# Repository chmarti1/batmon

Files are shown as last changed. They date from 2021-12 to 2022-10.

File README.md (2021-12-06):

#BatMon

A battery monitor system using the LabJack U3 DAQ
---
## In this README
- About
- License
- Warnings

## About
This repository includes files for a PC board design, Bill-of-Materials (BOM), and code for monitoring a battery from a Linux computer.  These materials are intended for information and inspiration; they do not constitute a complete instruction set.

The designed system uses a U3 DAQ to perform analog measurements and a temperature -measurement.  A shunt resistor provides small (+/-0.1V) signal indicating current to and from the battery, and direct connection to the battery terminals provides a measurement of the battery voltage.

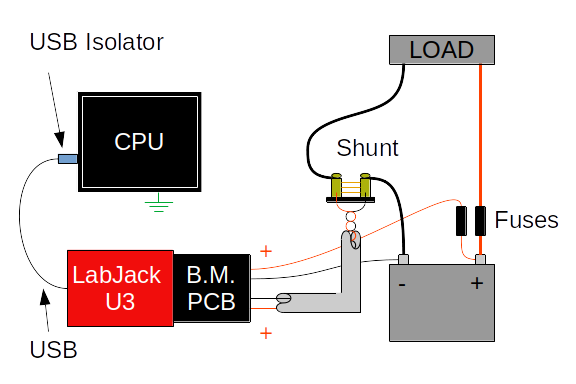
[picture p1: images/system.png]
System Diagram

**Figure 1** A system overview

I designed this system on a 12V AGM SLA battery, but it can be applied on battery arrays of other chemistries as well.

## License
BatMon: A battery monitoring system using the LabJack U3.  
Copyright (c) 2021 Christopher R. Martin PhD

These materials are released under the [GNU GPLv3](https://www.gnu.org/licenses/gpl-3.0.en.html).  This program is free software: you can redistribute it and/or modify it under the terms of the GNU General Public License as published by the Free Software Foundation, either version 3 of the License, or (at your option) any later version.

This program is distributed in the hope that it will be useful, but WITHOUT ANY WARRANTY; without even the implied warranty of MERCHANTABILITY or FITNESS FOR A PARTICULAR PURPOSE.  See the GNU General Public License for more details.

You should have received a copy of the GNU General Public License along with this program.  If not, see https://www.gnu.org/licenses/gpl-3.0.en.html .

## Warnings
- Working with power electronics can be dangerous and should only be done by qualified individuals.
- Special care should be taken to avoid accidental short-circuits
- This work is shared without warranty or suitability for a specific purpose.  
- This work should not be used in systems where failure may cause injury, loss of life, or damage to property.
- The performance of the designs shared here depend on workmanship and the sufficient care taken during calibration and installation.
- For safety, all connections to the positive terminal of the battery should be fused to limit the flow of current.

## Circuit

The circuit design is shown in [circuit.pdf](./images/circuit.pdf), and the PC board layout is shown below.  The DB-15 connector on the right-hand side connects to the LabJack U3 DB-15 connection.  There are four screw terminals on the left-hand side that permit the shunt and terminal measurements.  All inputs are reverse polarity and over-voltage tolerant up to 50V.

There are five low-current indicator LEDs (two red and three green).  The first red LED is tied to a special ALARM circuit, which also fires a buzzer.  The buzzer can be switched off manually by a toggle switch mounted at SW1 (every buzzer needs an off switch).

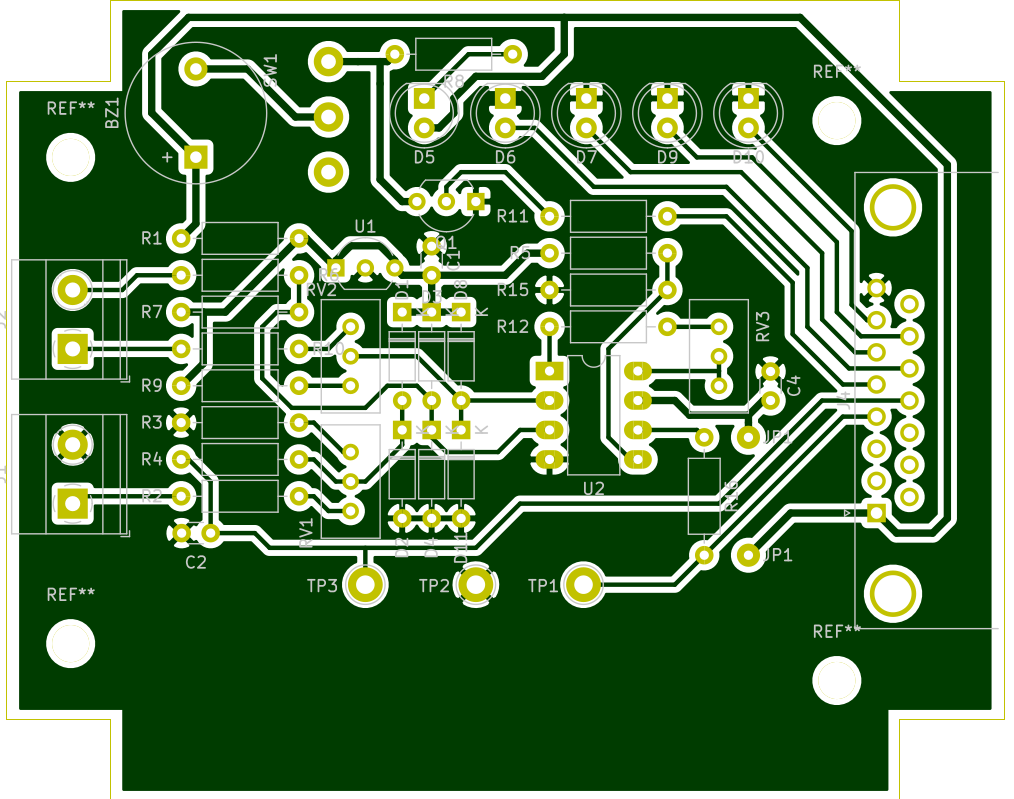
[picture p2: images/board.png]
Board Design


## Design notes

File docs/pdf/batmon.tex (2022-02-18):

\documentclass{article}

\title{The BATMON dynamic battery model}
\author{Christopher R. Martin}
\date{\today}

\begin{document}

\maketitle

\section{Electrical Model}

\end{document}

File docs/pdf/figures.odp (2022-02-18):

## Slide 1

+ Voltage Loss (VL) -

R1

R2

+

Open-Circuit Voltage

(VOC)

+

+

Terminal Voltage

(VT)

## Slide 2

CURRENT

LOAD

Initial internal resistance

tC

Final internal resistance

TIME

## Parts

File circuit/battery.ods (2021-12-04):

Reference | Quantity | Order | Value | Digikey PN (primary) | Digikey PN (secondary) | Footprint
BZ1 | 1 | 1 | CMI-1295IC-0585T | 2223-CMI-1295IC-0585T-ND |  | Buzzer_Beeper:Buzzer_12x9.5RM7.6 | EVERY device with a buzzer should have an ALARM OFF switch.
C4 C1 C2 | 3 |  | 1u | BC1168TR-ND |  | Capacitor_THT:C_Disc_D3.0mm_W1.6mm_P2.50mm
D1 D2 D3 D4 D11 D8 | 6 | 10 | 1N3595 | 1N3595-ND |  | Diode_THT:D_DO-35_SOD27_P7.62mm_Horizontal
D5 D6 | 2 | 1 | RED,10mA | 516-1328-ND |  | LED_THT:LED_D5.0mm
D7 D9 D10 | 3 | 1 | GREEN,10mA | 516-1333-ND |  | LED_THT:LED_D5.0mm
J1 J2 | 2 | 2 | Conn_01x02 | 277-1247-ND |  | TerminalBlock_Phoenix:TerminalBlock_Phoenix_MKDS-1,5-2-5.08_1x02_P5.08mm_Horizontal
J4 | 1 | 1 | DB15_Male | 609-1492-ND |  | Connector_Dsub:DSUB-15_Male_Horizontal_P2.77x2.84mm_EdgePinOffset7.70mm_Housed_MountingHolesOffset9.12mm
Q1 | 1 | 1 | PN2222 | PN2222AFS-ND |  | Package_TO_SOT_THT:TO-92_Inline_Wide
R1 | 1 |  | 470 |  |  | Resistor_THT:R_Axial_DIN0207_L6.3mm_D2.5mm_P10.16mm_Horizontal
R12 | 1 |  | 4K7 |  |  | Resistor_THT:R_Axial_DIN0207_L6.3mm_D2.5mm_P10.16mm_Horizontal
R16 R4 | 2 |  | 100 |  |  | Resistor_THT:R_Axial_DIN0207_L6.3mm_D2.5mm_P10.16mm_Horizontal
R3 | 1 | 2 | 1K2_1% | S1.2KCATR-ND |  | Resistor_THT:R_Axial_DIN0207_L6.3mm_D2.5mm_P10.16mm_Horizontal
R5 R2 R15 R7 R6 R9 R10 | 7 | 10 | 10K_1% | RNF14FTD10K0TR-ND |  | Resistor_THT:R_Axial_DIN0207_L6.3mm_D2.5mm_P10.16mm_Horizontal
R8 R11 | 2 | 2 | 270 |  |  | Resistor_THT:R_Axial_DIN0207_L6.3mm_D2.5mm_P10.16mm_Horizontal
RV1 RV2 RV3 | 3 | 3 | 1K, 3362P | 490-2874-ND |  | Potentiometer_THT:Potentiometer_Bourns_3296W_Vertical
SW1 | 1 | 1 | ANT11SF1CQE | 2449-ANT11SF1CQE-ND |  | _batmon:SW_CIT_ANT_SPDT
TP1 TP2 TP3 | 3 | 3 | TestPoint | 36-5280-ND | 36-5281-ND | TestPoint:TestPoint_Loop_D2.60mm_Drill1.6mm_Beaded
U1 | 1 | 1 | TL431LP | 497-15786-1-ND |  | Package_TO_SOT_THT:TO-92_Inline_Wide
U2 | 1 | 1 | AD623AN | 505-AD623BNZ-ND | A120347-ND | Package_DIP:DIP-8_W7.62mm_LongPads
BOX | 1 | 1 | Hammond 1593BBBK | HM1375-ND
SHUNT | 1 | 1 | 1mOhm, .25% | 811-1094-ND
RING TERMINAL, SM | 2 | 25 | #8, 14-16AWG
RING TERMINAL, LG | 6 | 10 | 3/8 4AWG

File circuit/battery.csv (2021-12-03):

Reference | Quantity | Value | Footprint | Datasheet
BZ1 | 1 | CMI-1295IC-0585T | Buzzer_Beeper:Buzzer_12x9.5RM7.6 | ~
C4 C1 C2 | 3 | 1u | Capacitor_THT:C_Disc_D3.0mm_W1.6mm_P2.50mm | ~
D1 D2 D3 D4 D11 D8 | 6 | 1N3595 | Diode_THT:D_DO-35_SOD27_P7.62mm_Horizontal | ~
D5 D6 | 2 | RED,10mA | LED_THT:LED_D5.0mm | ~
D7 D9 D10 | 3 | GREEN,10mA | LED_THT:LED_D5.0mm | ~
J1 J2 | 2 | Conn_01x02 | TerminalBlock_Phoenix:TerminalBlock_Phoenix_MKDS-1,5-2-5.08_1x02_P5.08mm_Horizontal | ~
J4 | 1 | DB15_Male | Connector_Dsub:DSUB-15_Male_Horizontal_P2.77x2.84mm_EdgePinOffset7.70mm_Housed_MountingHolesOffset9.12mm | ~
Q1 | 1 | BS107 | Package_TO_SOT_THT:TO-92_Inline_Wide | http://www.onsemi.com/pub_link/Collateral/BS107-D.PDF
R1 | 1 | 500 | Resistor_THT:R_Axial_DIN0207_L6.3mm_D2.5mm_P10.16mm_Horizontal | ~
R12 | 1 | 4K7 | Resistor_THT:R_Axial_DIN0207_L6.3mm_D2.5mm_P10.16mm_Horizontal | ~
R16 R4 | 2 | 100 | Resistor_THT:R_Axial_DIN0207_L6.3mm_D2.5mm_P10.16mm_Horizontal | ~
R3 | 1 | 1K2_1% | Resistor_THT:R_Axial_DIN0207_L6.3mm_D2.5mm_P10.16mm_Horizontal | ~
R5 R2 R15 R7 R6 R9 R10 | 7 | 10K_1% | Resistor_THT:R_Axial_DIN0207_L6.3mm_D2.5mm_P10.16mm_Horizontal | ~
R8 | 1 | 300 | Resistor_THT:R_Axial_DIN0207_L6.3mm_D2.5mm_P10.16mm_Horizontal | ~
RV1 RV2 RV3 | 3 | 1K, 3362P | Potentiometer_THT:Potentiometer_Bourns_3296W_Vertical | ~
SW1 | 1 | ANT11SF1CQE | _batmon:SW_CIT_ANT_SPDT | ~
TP1 TP2 TP3 | 3 | TestPoint | TestPoint:TestPoint_Loop_D2.60mm_Drill1.6mm_Beaded | ~
U1 | 1 | TL431LP | Package_TO_SOT_THT:TO-92_Inline_Wide | http://www.ti.com/lit/ds/symlink/tl431.pdf
U2 | 1 | AD623AN | Package_DIP:DIP-8_W7.62mm_LongPads | https://www.analog.com/media/en/technical-documentation/data-sheets/AD623.pdf

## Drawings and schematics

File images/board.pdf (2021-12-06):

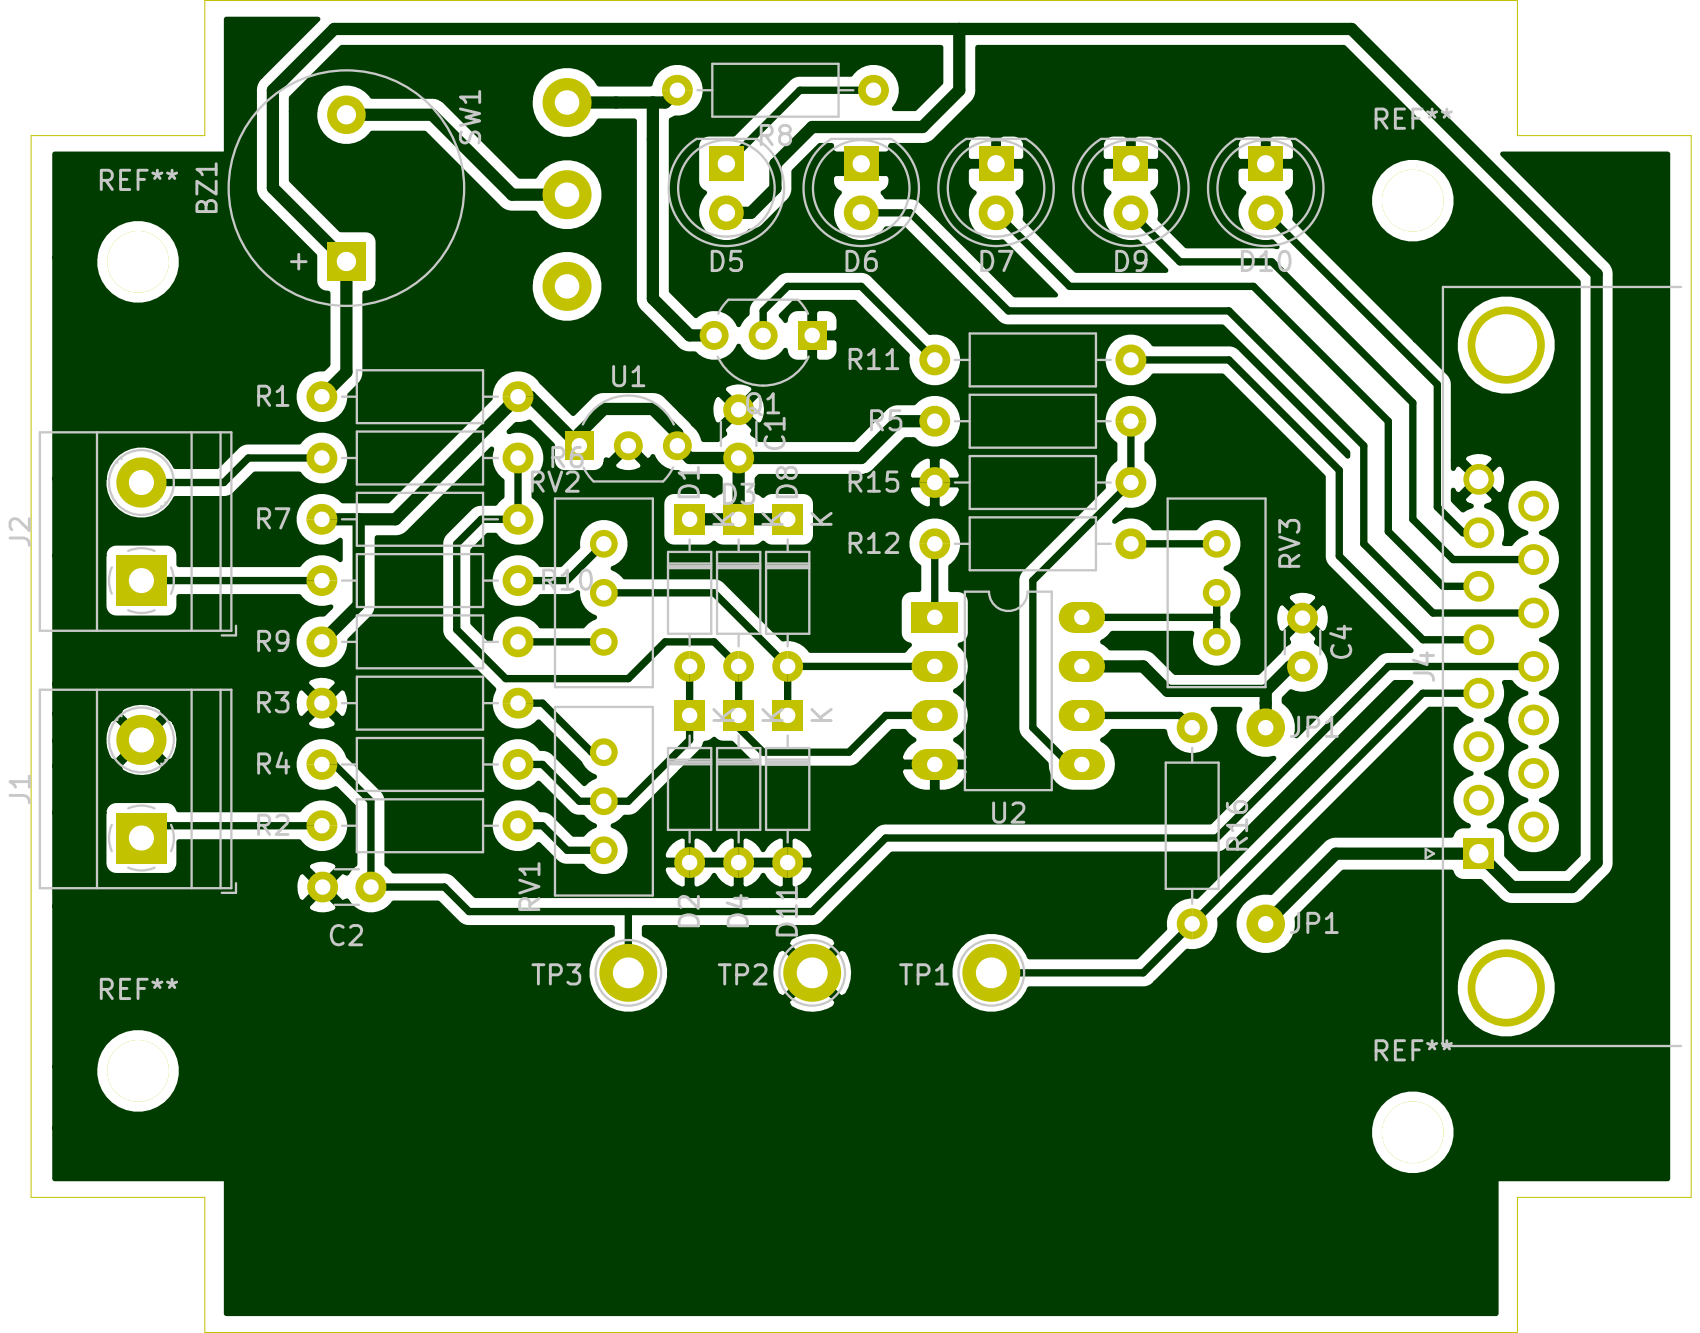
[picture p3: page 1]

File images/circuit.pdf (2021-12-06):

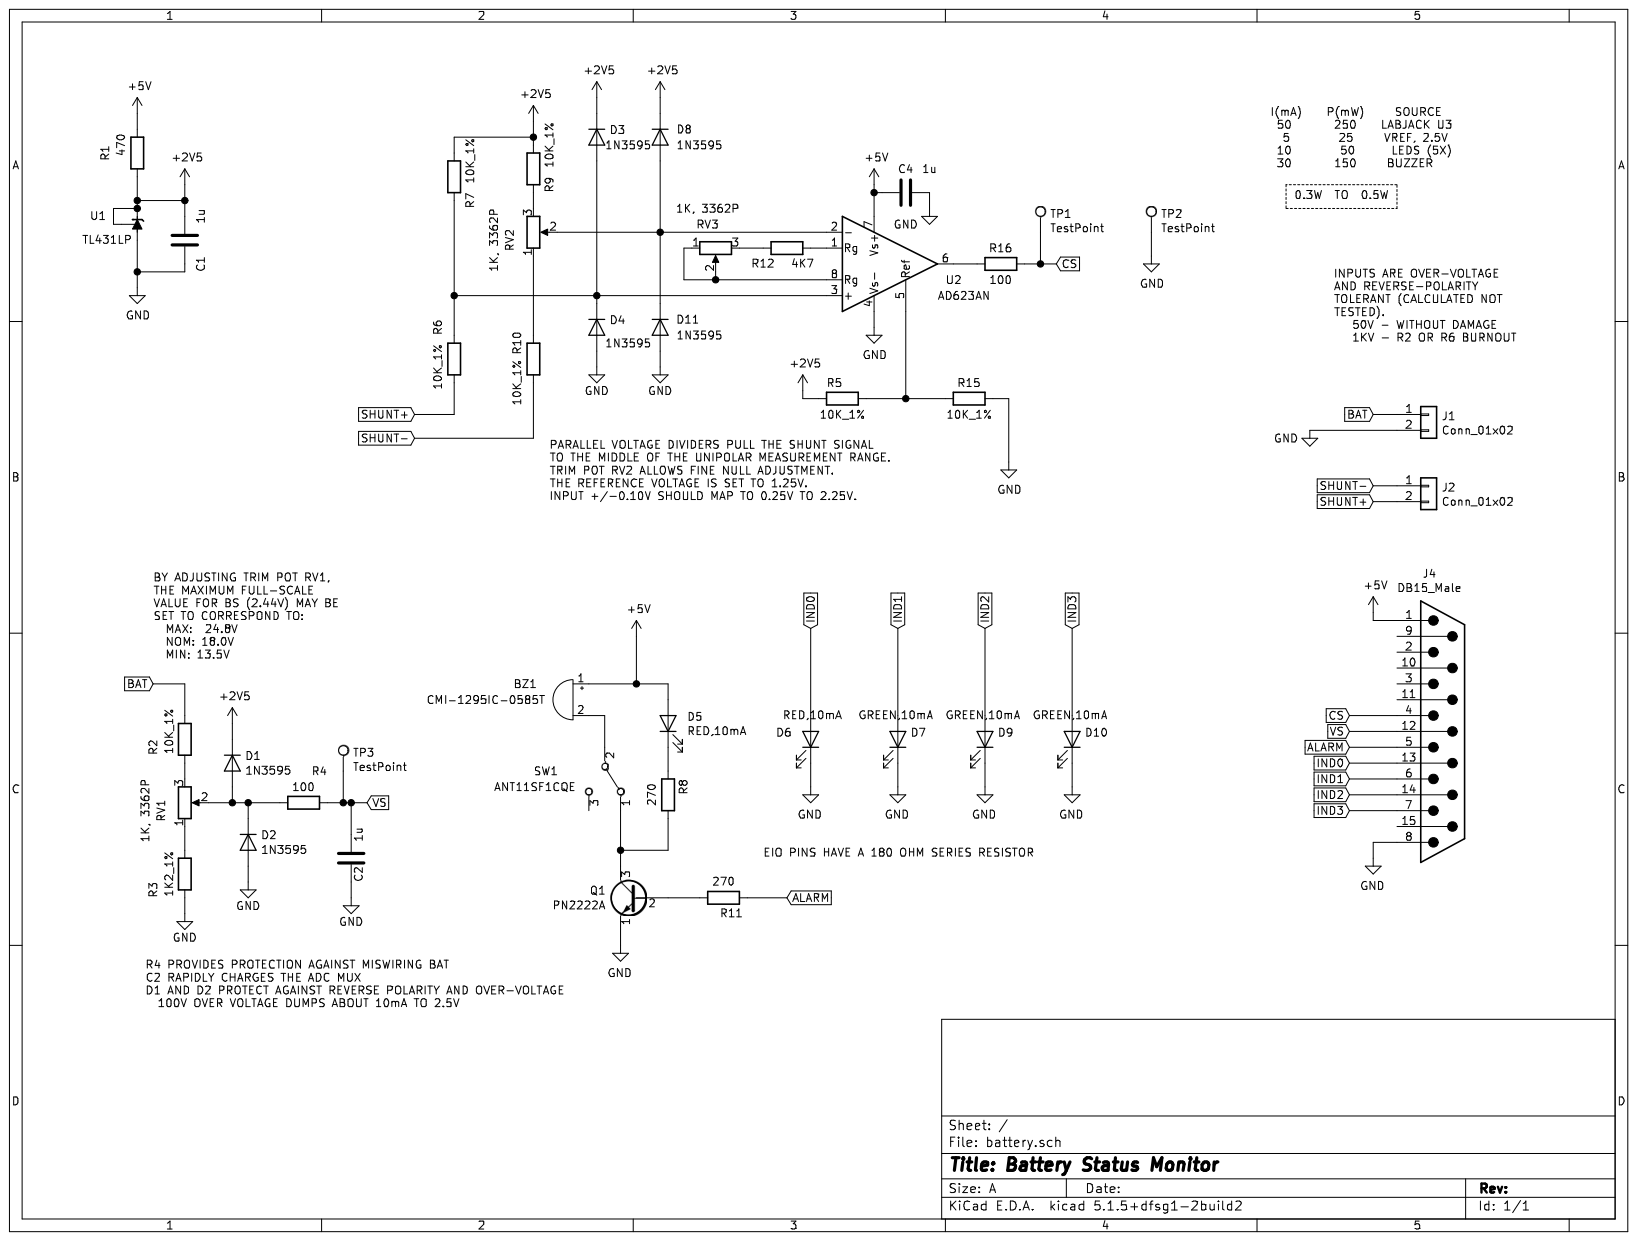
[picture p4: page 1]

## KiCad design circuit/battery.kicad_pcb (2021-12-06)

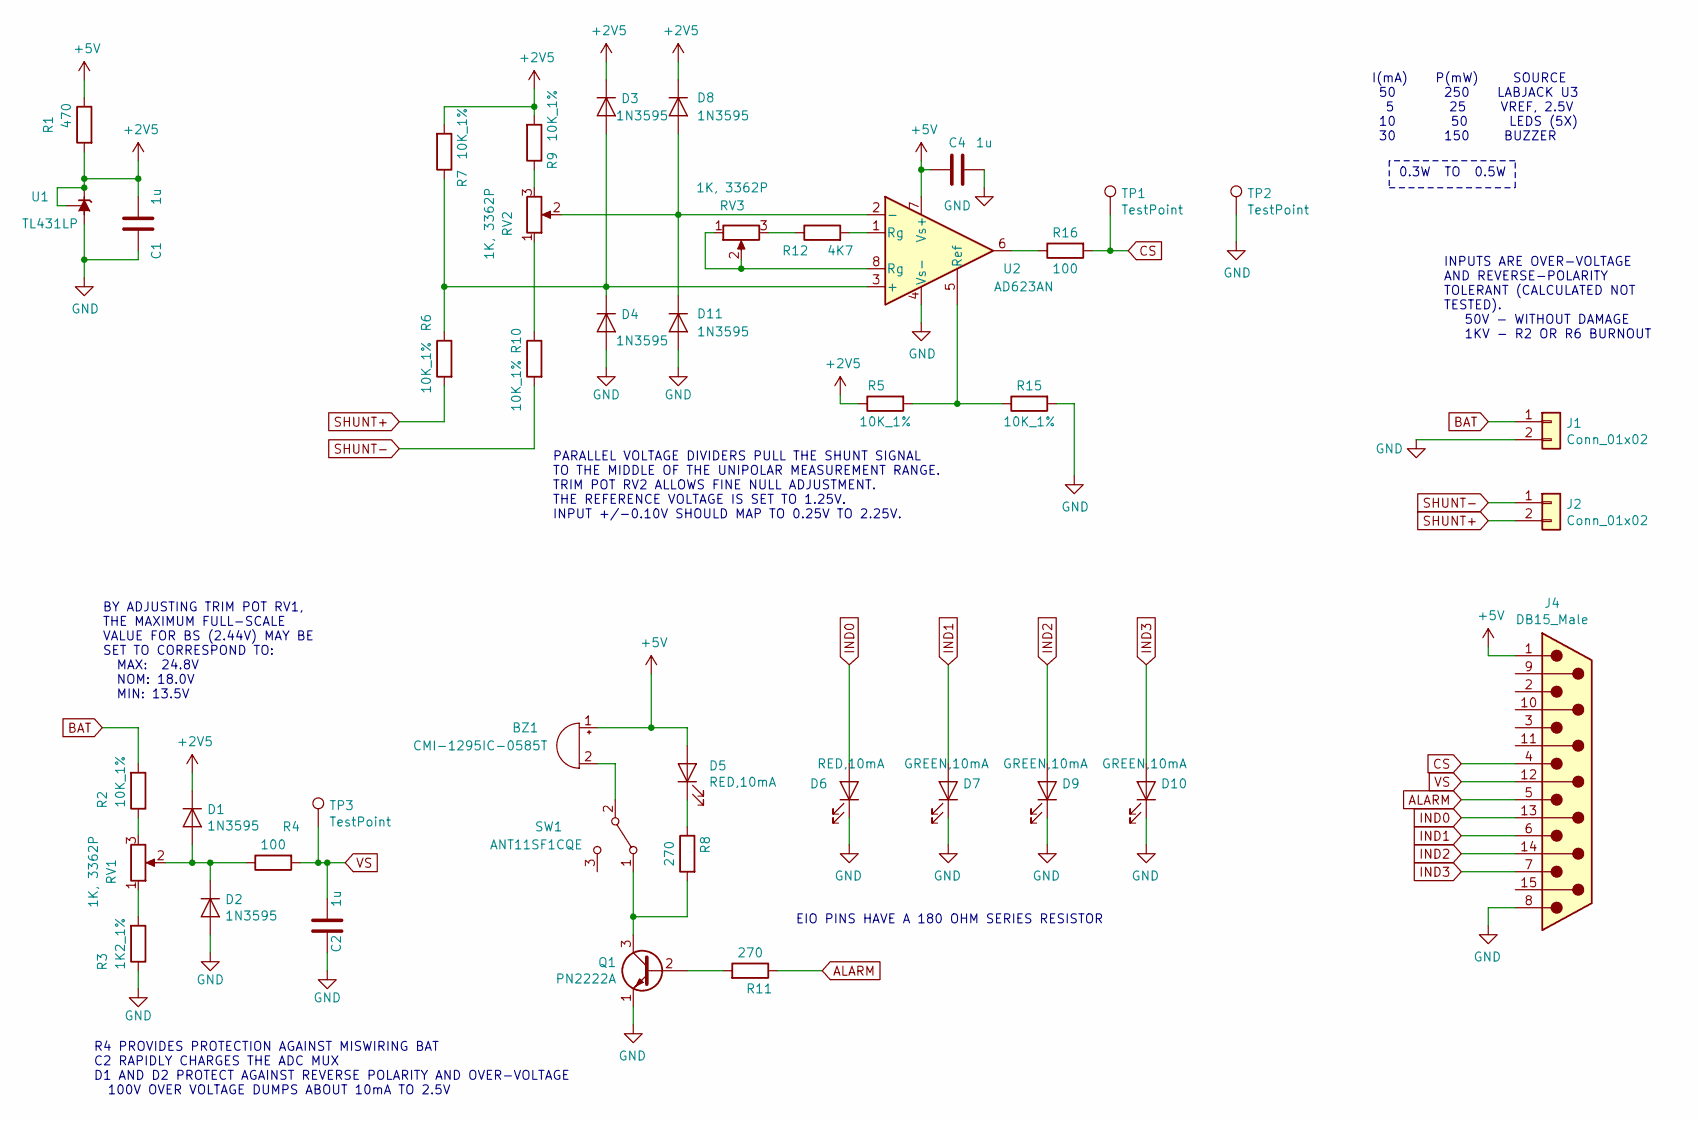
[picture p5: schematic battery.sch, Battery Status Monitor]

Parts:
BZ1: CMI-1295IC-0585T; Buzzer_12x9.5RM7.6
C1, C2, C4: 1u; C_Disc_D3.0mm_W1.6mm_P2.50mm
D1, D2, D3, D4, D8, D11: 1N3595; D_DO-35_SOD27_P7.62mm_Horizontal
D5, D6: RED,10mA; LED_D5.0mm
D7, D9, D10: GREEN,10mA; LED_D5.0mm
J1, J2: Conn_01x02; TerminalBlock_Phoenix_MKDS-1,5-2-5.08_1x02_P5.08mm_Horizont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
J4: DB15_Male; DSUB-15_Male_Horizontal_P2.77x2.84mm_EdgePinOffset7.70mm_Ho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
Q1: PN2222A; TO-92_Inline_Wide
R1: 470; R_Axial_DIN0207_L6.3mm_D2.5mm_P10.16mm_Horizontal
R2, R5, R6, R7, R9, R10, R15: 10K_1%; R_Axial_DIN0207_L6.3mm_D2.5mm_P10.16mm_Horizontal
R3: 1K2_1%; R_Axial_DIN0207_L6.3mm_D2.5mm_P10.16mm_Horizontal
R4, R16: 100; R_Axial_DIN0207_L6.3mm_D2.5mm_P10.16mm_Horizontal
R8, R11: 270; R_Axial_DIN0207_L6.3mm_D2.5mm_P10.16mm_Horizontal
R12: 4K7; R_Axial_DIN0207_L6.3mm_D2.5mm_P10.16mm_Horizontal
RV1, RV2, RV3: 1K, 3362P; Potentiometer_Bourns_3296W_Vertical
SW1: ANT11SF1CQE; SW_CIT_ANT_SPDT
TP1, TP2, TP3: TestPoint; TestPoint_Loop_D2.60mm_Drill1.6mm_Beaded
U1: TL431LP; TO-92_Inline_Wide
U2: AD623AN; DIP-8_W7.62mm_LongPads

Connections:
+2V5: C1.1, D1.1 (K), D3.1 (K), D8.1 (K), R1.2, R5.1, R7.2, R9.2, U1.1 (REF), U1.3 (K)
+5V: BZ1.1 (-), C4.2, D5.2 (A), J4.1, R1.1, U2.7 (Vs+); also elsewhere on the board
ALARM: J4.5, R11.1
BAT: J1.1, R2.2
CS: J4.4, R16.2, TP1.1
GND: C1.2, C2.1, C4.1, D2.2 (A), D4.2 (A), D6.1 (K), D7.1 (K), D9.1 (K), D10.1 (K), D11.2 (A), J1.2, J4.8, Q1.1 (E), R3.1, R15.2, TP2.1, U1.2 (A), U2.4 (Vs-)
IND0: D6.2 (A), J4.13
IND1: D7.2 (A), J4.6
IND2: D9.2 (A), J4.14
IND3: D10.2 (A), J4.7
unnamed: BZ1.2 (+), SW1.2 (B)
unnamed: D1.2 (A), D2.1 (K), R4.1, RV1.2
unnamed: D3.2 (A), D4.1 (K), R6.1, R7.1, U2.3 (+)
unnamed: D5.1 (K), R8.1
unnamed: D8.2 (A), D11.1 (K), RV2.2, U2.2 (-)
unnamed: Q1.2 (B), R11.2
unnamed: Q1.3 (C), R8.2, SW1.1 (A)
unnamed: R2.1, RV1.3
unnamed: R3.2, RV1.1
unnamed: R9.1, RV2.3
unnamed: R10.1, RV2.1
unnamed: R12.1, RV3.3
unnamed: R12.2, U2.1 (Rg)
unnamed: R5.2, R15.1, U2.5 (Ref)
unnamed: R16.1, U2.6
unnamed: RV3.1, RV3.2, U2.8 (Rg)
SHUNT+: J2.2, R6.2
SHUNT-: J2.1, R10.2
VS: C2.2, J4.12, R4.2, TP3.1

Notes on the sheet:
BY ADJUSTING TRIM POT RV1, THE MAXIMUM FULL-SCALE VALUE FOR BS (2.44V) MAY BE SET TO CORRESPOND TO: MAX: 24.8V NOM: 18.0V MIN: 13.5V
R4 PROVIDES PROTECTION AGAINST MISWIRING BAT C2 RAPIDLY CHARGES THE ADC MUX D1 AND D2 PROTECT AGAINST REVERSE POLARITY AND OVER-VOLTAGE 100V OVER VOLTAGE DUMPS ABOUT 10mA TO 2.5V
PARALLEL VOLTAGE DIVIDERS PULL THE SHUNT SIGNAL TO THE MIDDLE OF THE UNIPOLAR MEASUREMENT RANGE. TRIM POT RV2 ALLOWS FINE NULL ADJUSTMENT. THE REFERENCE VOLTAGE IS SET TO 1.25V. INPUT +/-0.10V SHOULD MAP TO 0.25V TO 2.25V.
EIO PINS HAVE A 180 OHM SERIES RESISTOR
I(mA) P(mW) SOURCE 50 250 LABJACK U3 5 25 VREF, 2.5V 10 50 LEDS (5X) 30 150 BUZZER
0.3W TO 0.5W
INPUTS ARE OVER-VOLTAGE AND REVERSE-POLARITY TOLERANT (CALCULATED NOT TESTED). 50V - WITHOUT DAMAGE 1KV - R2 OR R6 BURNOUT

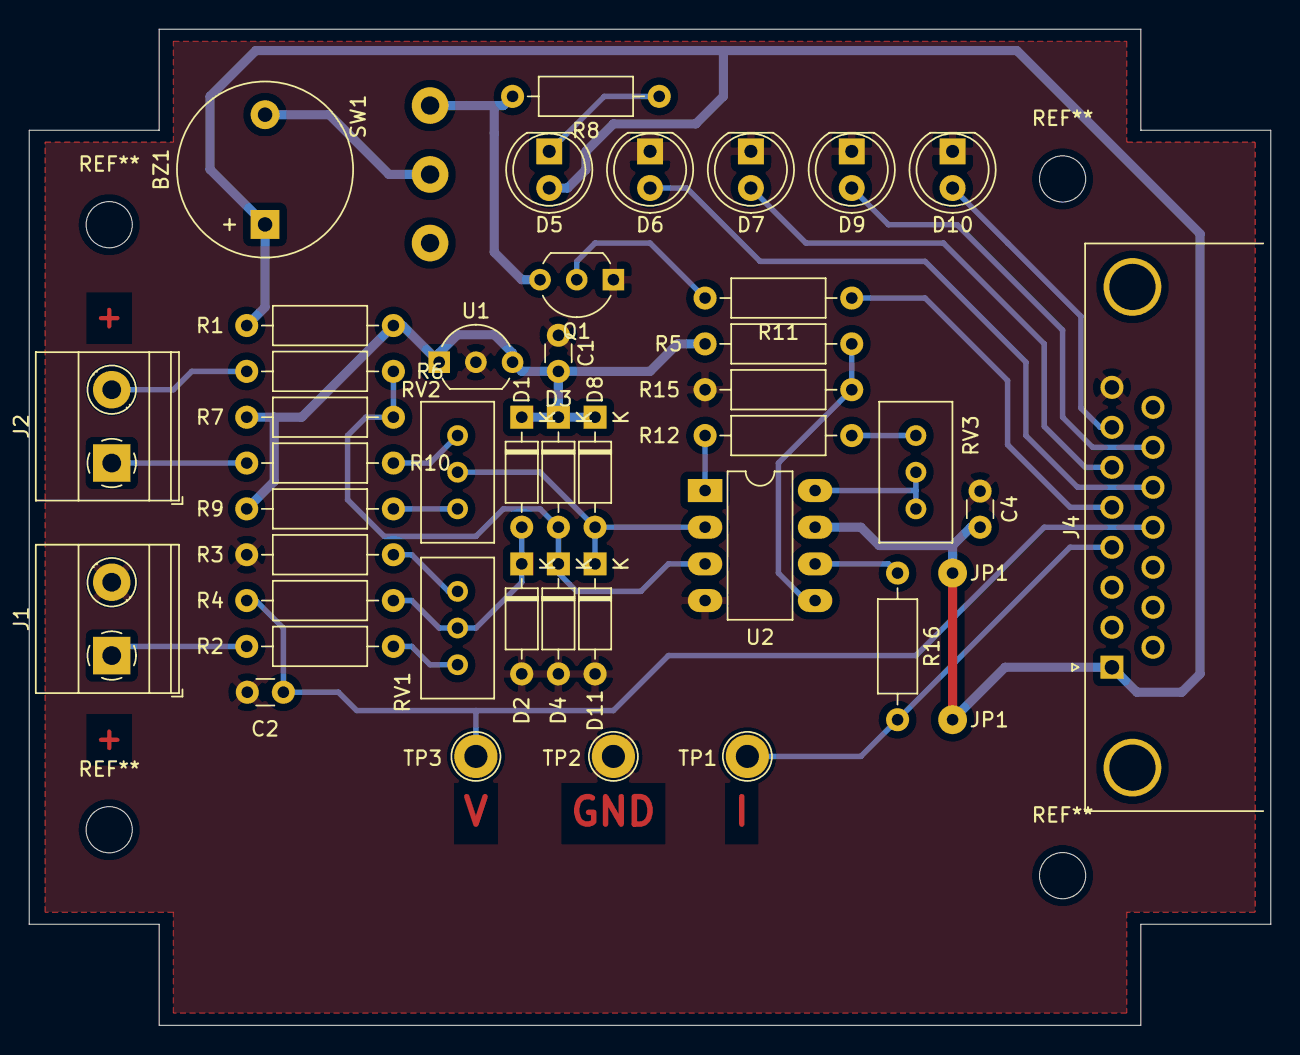
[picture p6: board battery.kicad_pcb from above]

Board: 2 copper layers, 86.0 x 69.0 mm, 44 parts (0 on the bottom side), 29 nets.

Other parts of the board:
JP1, JP1#2: SolderWirePad_1x01_Drill0.8mm

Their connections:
+5V: JP1.1, JP1#2.1; also elsewhere on the board

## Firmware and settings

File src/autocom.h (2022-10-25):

/* AUTOCOM.H
 * 
 * Header for wrapper codes to automate communication operations with 
 * the LabJack U3.  These are written to be specific to the BatMon 
 * application.
 */


#ifndef __AUTOCOM_H__
#define __AUTOCOM_H__

#include <labjackusb.h>
#include <stdio.h>
#include <stdint.h>
#include "chargemodel.h"

// Analog stream prameters
#define AC_CHANNELS             3
#define AC_AICLOCK_HZ           48e6
#define AC_BITSTATE_MASK        0x80        // Pin 7 is the bit state/direction bit in the bit direction/state commands
#define AC_EIO_OFFSET           8           // The EIO pins are 8-15, so there is an offset of 8 for the pin numbers.
#define AC_STRLEN               128         // The longest string length allowed

typedef enum _acchannel_t {
    ACCHAN_CURRENT = 0,
    ACCHAN_VOLTAGE = 1,
    ACCHAN_TEMPERATURE = 2,
} acchannel_t;

/* ACPIN_T - The pin number type
 *  Establishes constants for the pin numbers
 */
typedef enum _acpin_t {
    ACPIN_NONE =    -1,
    ACPIN_CS =      0,
    ACPIN_VS =      1,
    ACPIN_ALARM =   2,
    ACPIN_IND0 =    3,
    ACPIN_IND1 =    4,
    ACPIN_IND2 =    5,
    ACPIN_IND3 =    6,
    ACPIN_T =       30 - AC_EIO_OFFSET,
} acpin_t;


/* ACERROR_T- the error code type
 *  Establishes constants for function return values
 */
typedef enum _acerror_t {
    ACERR_NONE =            0,          // Everything is OK
    // Generic Errors
    ACERR_DEV_NOT_OPEN =    0x10,       // The device handle is NULL
    ACERR_BAD_CHECKSUM =    0x11,       // There was a bad checksum
    ACERR_CORRUPT_BUFFER =  0x12,       // Some aspect of the data in the buffer is invalid
    ACERR_TX_FAILURE =      0x13,       // Transmit or receive failed 
    ACERR_RX_FAILURE =      0x14,       //   
    ACERR_RX_LENGTH =       0x15,       // Reply length was unexpected
    ACERR_PARAM_ERROR =     0x16,       // A function argument was illegal

    // Configuration errors
    ACERR_CONFIG_FILE =     0x20,       // Configuration file was not opened
    ACERR_CONFIG_SYNTAX =   0x21,       // Illegally formatted configuration file
    ACERR_LSD_FILE =        0x22,       // Could not open the log, stat, or datafile

    // Init/Open Errors
    ACERR_DEV_ALREADY_OPEN = 0x30,      // Init was run twice
    ACERR_OPEN_FAILED =     0x31,       // Open operation failed
    ACERR_CONFIG_FAILED =   0x32,       // Failed while configuring IO
    
    // Stream Errors
    ACERR_AICONFIG_FAILED = 0x40,
    ACERR_AISTART_FAILED =  0x41,
    ACERR_AIREAD_FAILED =   0x42,
    ACERR_AISTOP_FAILED =   0x43,
    
} acerror_t;


typedef enum _acloglevel_t{
    ACLOG_ESSENTIAL = -1,
    ACLOG_LOW = 0,
    ACLOG_MEDIUM = 1,
    ACLOG_HIGH = 2,
} acloglevel_t;

// These are masks constructed from the relevant EIO pin numbers
// --> EIO Analog input mask 8-bits with 1 for AIN pins
#define AC_EIOAIN_MASK  (1<<ACPIN_CS | 1<<ACPIN_VS) // These are the analog
// --> EIO Digital output mask 8-bits with 1 for digital outputs
#define AC_EIODOUT_MASK (1<<ACPIN_ALARM | 1<<ACPIN_CS | 1<<ACPIN_IND0 | 1<<ACPIN_IND1 | 1<<ACPIN_IND2 | 1<<ACPIN_IND3)


/* ACDEV_T - The device struct
 * 
 */
typedef struct _acdev_t {
    // Device handle
    HANDLE handle;
    // Files
    char logfile[AC_STRLEN];
    char statfile[AC_STRLEN];
    char datafile[AC_STRLEN];

    // Log level
    acloglevel_t loglevel;

    // Descriptive
    float firmware_version;
    float bootloader_version;
    float hardware_version;
    unsigned int serial_number;
    // Calibration
    // Device calibration
    double ain_slope;
    double ain_offset;
    // Device temperature calibration
    double temp_slope;
    // Current
    double current_slope;
    double current_zero;
    // Voltage
    double voltage_slope;
    double voltage_zero;
    
    // data record interval
    double tdata;
    // AI sample interval
    double tsample;
    // AI sample count
    uint8_t Nsample;
    
    // Stream status parameters
    unsigned int aistr_backlog;
    unsigned int aistr_active:1;
} acdev_t;


/* ACMESSAGE - Log a message
 *  acmessage_send pushes text to a log location.  If no log file has 
 * been configured for the device, then stdout is used.  If the 
 * dev->logfile path is defined, it attempts to open the file, append to
 * it, and close the file.  If that process fails, a message is sent to 
 * stderr and the original message is sent to stdout.
 * 
 * Messages will have an integer "[TIMESTAMP]" prepended (seconds since 
 * the epoch), and a newline appended.  
 * 
 * The message's log level is specified by the "level" enum.  Messages
 * that are higher than the devices configured dev->loglevel value will
 * be ignored.  Messages with lower values will be sent.  Negative 
 * values will always be sent.
 */
acerror_t acmessage(acdev_t *dev, char *text, acloglevel_t level);

/* ACDATA - Log a data entry
 *  The ACDATA() function is responsible for tending to the data file.
 * If the file does not exist, it creates the file with a header.  
 * Each time ACDATA is called, it appends a line to the file with the
 * system time in seconds (since the epoch) and appropriate whitespace
 * separated columns.
 * 
 * If the operation fails, the ACERR_LSD_FILE error condition is 
 * returned.
 */
acerror_t acdata(acdev_t *dev, cmbat_t *bat);

/* ACERROR - Construct a meaningful message based on the error number
 *  Writes an error message no longer than AC_STRLEN to target to 
 * describe the error found in err.  If the error is unrecognized, an
 * appropriate message is written.
 */
void acerror(acerror_t err, char *target);

/* ACCONFIG - Load a device configuration file
 * 
 * This initializes the device configuration struct and all its members
 * (including the battery model) before loading the configuration file.
 */
acerror_t acconfig(acdev_t *dev, char *filename);

/* ACOPEN - Open a connection to the device
 */
acerror_t acopen(acdev_t *dev);
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

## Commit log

2021-12-04 Final board design; production complete
    [battery.ods, battery.sch]
2021-12-04 Placed digikey order
    [battery.ods, battery.sch]
2021-12-06 Started writing documentation
    [battery.kicad_pcb, battery.sch]
2021-12-30 started adding documentation to bmcmd
    [battery.sch]
2022-09-11 Rewrite of EVERYTHING for 60Hz cycle averaging
2022-09-15 Finally debugged streaming. Deveoping new chargemodel interface
2022-10-25 Prototype code ready for implementation
2022-10-25 Demonstrated working bmsvc.bin
